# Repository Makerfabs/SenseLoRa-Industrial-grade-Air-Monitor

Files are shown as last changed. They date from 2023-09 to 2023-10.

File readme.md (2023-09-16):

# SenseLoRa Industrial grade Air Monitor

```c++
/*
Version:		V1.0
Author:			Vincent
Create Date:	2023/9/16
Note:

*/
```
# Makerfabs

[Makerfabs home page](https://www.makerfabs.com/)

[Makerfabs Wiki](https://wiki.makerfabs.com/)

# How To Use

## Arduino Complier Option

**If you have any questions，such as how to install the development board, how to download the code, how to install the library. Please refer to :[Makerfabs_FAQ](https://github.com/Makerfabs/Makerfabs_FAQ)**

- Install board : ESP32 Version 2.0.11
- Select "ESP32-S3"
- Select Erase All Flash
- Upload codes

Arduino libraries:

- RadioLib 4.6.0
- Adafruit_Unified_Sensor 1.1.9
- Adafruit_AHT10 0.1.0
- Adafruit_BusIO 1.14.1
- Adafruit_SGP30_Sensor 2.0.0
- BH1750 1.3.0

## Lora Data Format

```json

{
	"ID": "AirM01",
	"COUNT": 22,
	"SLEEP": 3600,
	"bat": 3.48,
	"temp": 0.00,
	"humi": 0.00,
	"eco2": 0.00,
	"lux": 0.00
}

 ```

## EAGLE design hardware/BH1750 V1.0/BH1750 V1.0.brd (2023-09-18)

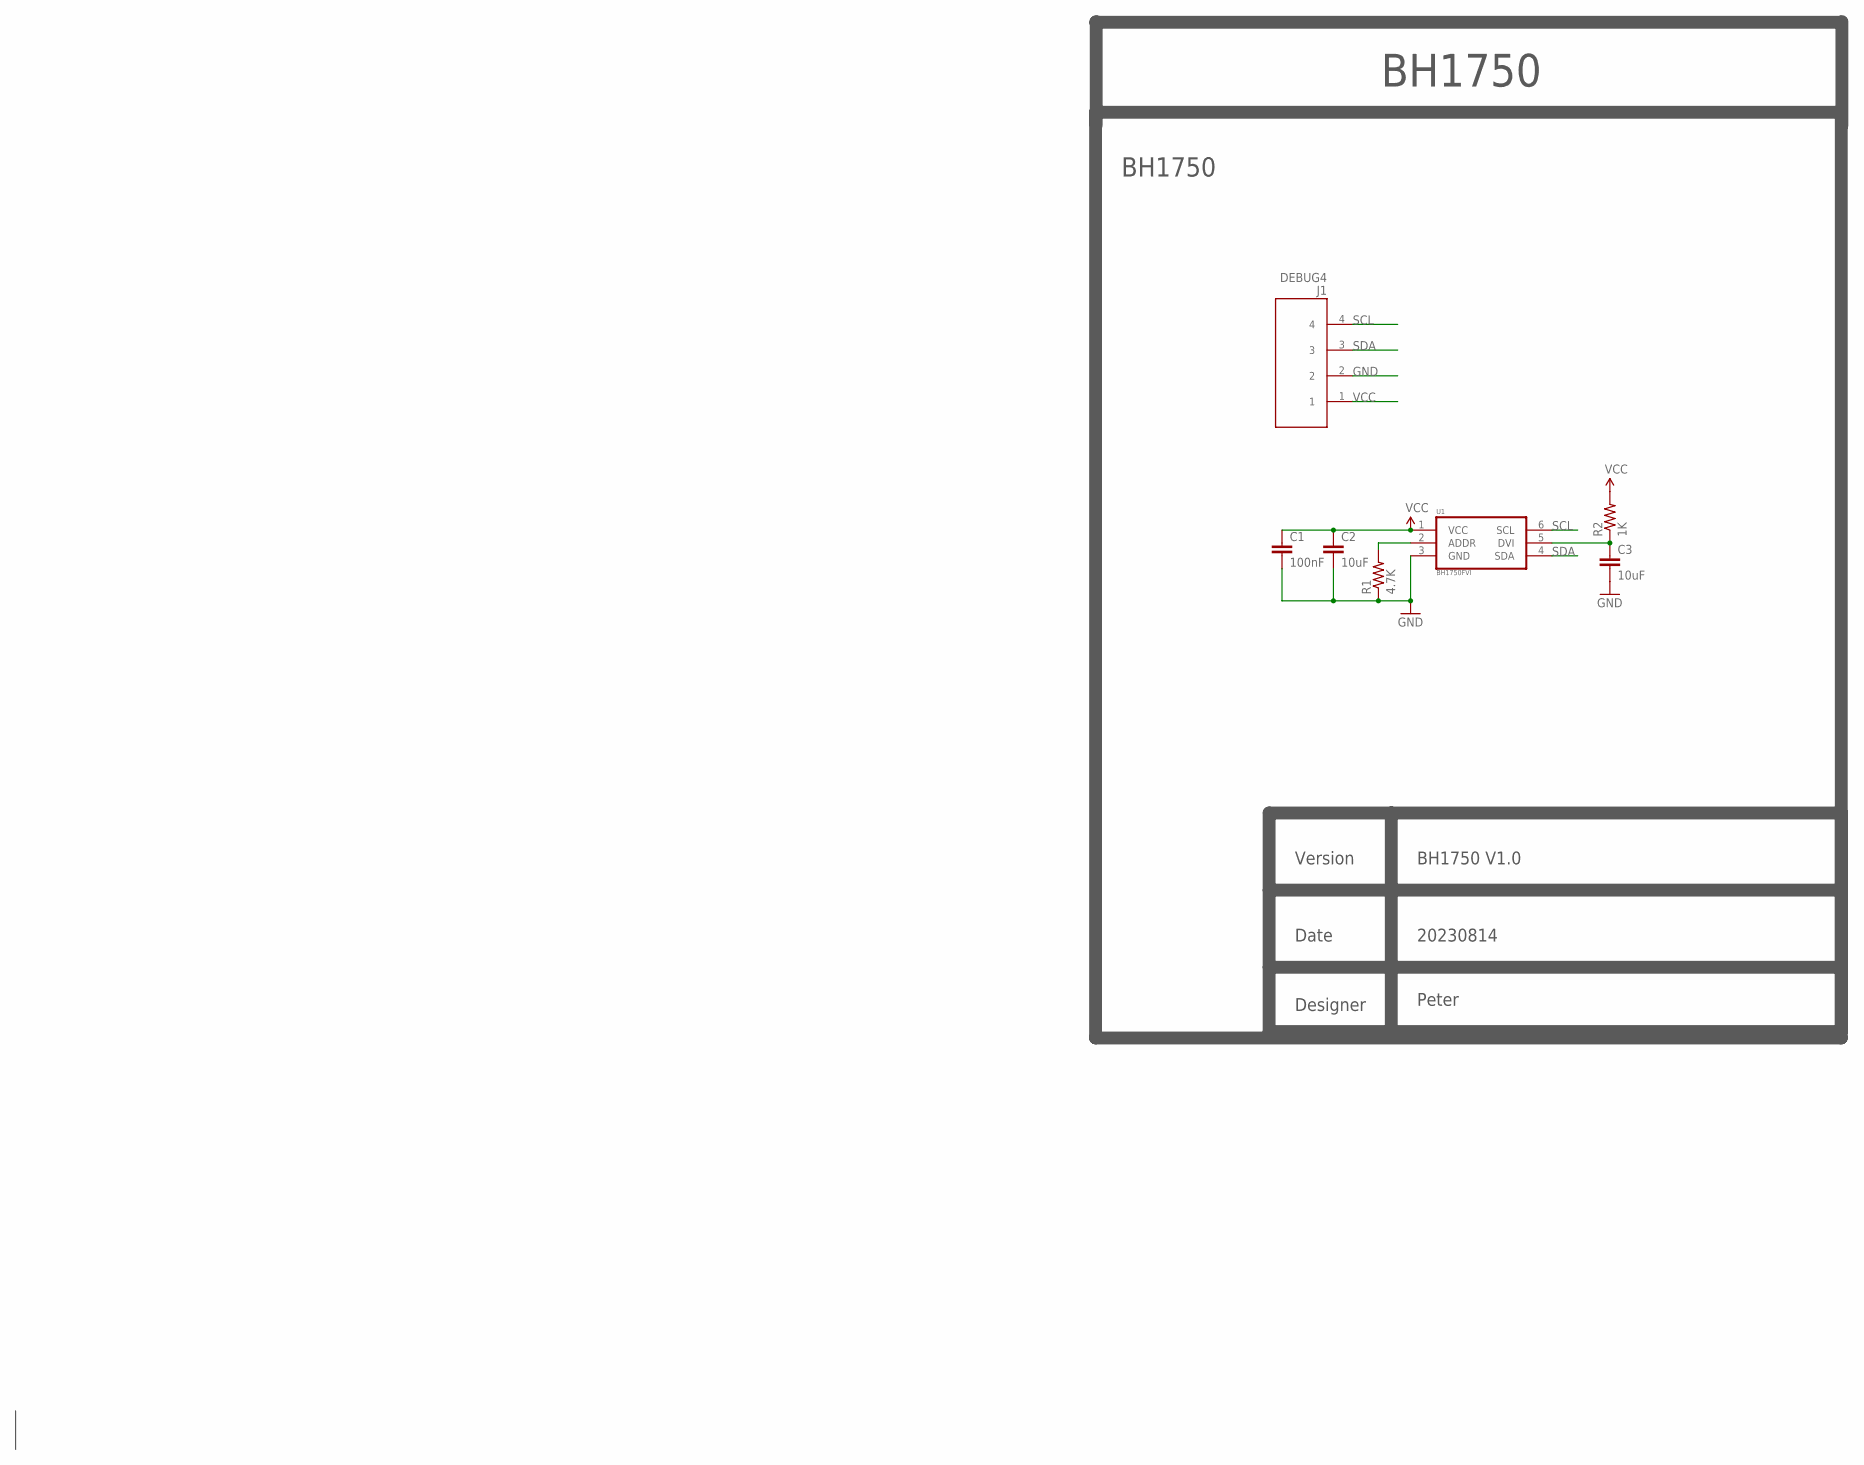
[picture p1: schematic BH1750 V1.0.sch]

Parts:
C1: 100nF; C0603
C2, C3: 10uF; C0603
J1: DEBUG4; DEBUG*4
R1: 4.7K; R0603
R2: 1K; R0603
U1: BH1750FVI; WSOF6I

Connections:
GND: C1.2, C2.2, C3.2, J1.2, R1.1, U1.3 (GND)
unnamed: C3.1, R2.1, U1.5 (DVI)
unnamed: R1.2, U1.2 (ADDR)
SCL: J1.4, U1.6 (SCL)
SDA: J1.3, U1.4 (SDA)
VCC: C1.1, C2.1, J1.1, R2.2, U1.1 (VCC)

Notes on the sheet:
BH1750
Version
Date
Designer
BH1750 V1.0
20230814
Peter

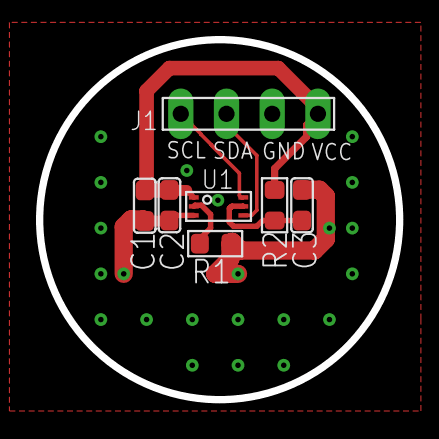
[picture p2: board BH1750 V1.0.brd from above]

Board: 2 copper layers, 20.0 x 20.0 mm, 7 parts (0 on the bottom side), 6 nets.

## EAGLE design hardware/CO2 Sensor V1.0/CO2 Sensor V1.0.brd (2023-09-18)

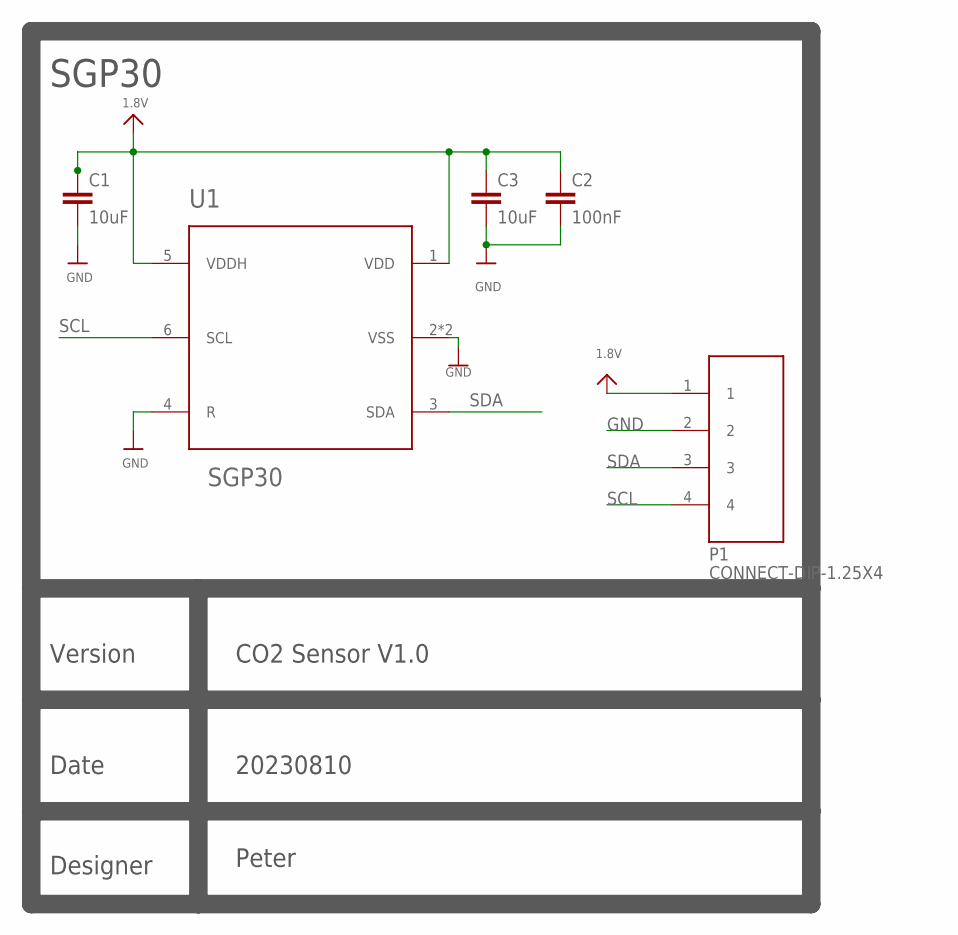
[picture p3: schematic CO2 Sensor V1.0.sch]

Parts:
C1, C3: 10uF; C0603
C2: 100nF; C0603
P1: CONNECT-DIP-1.25X4
U1: SGP30

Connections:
1.8V: C1.1, C2.1, C3.1, P1.1, U1.1 (VDD), U1.5 (VDDH)
GND: C1.2, C2.2, C3.2, P1.2, U1.2 (VSS), U1.4 (R), U1.P$7 (VSS)
SCL: P1.4, U1.6 (SCL)
SDA: P1.3, U1.3 (SDA)

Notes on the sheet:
Version
Date
Designer
CO2 Sensor V1.0
20230810
Peter
SGP30

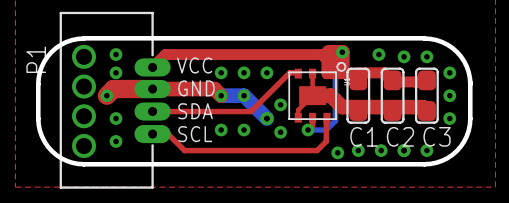
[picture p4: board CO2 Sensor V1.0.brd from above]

Board: 2 copper layers, 24.0 x 7.0 mm, 5 parts (0 on the bottom side), 4 nets.

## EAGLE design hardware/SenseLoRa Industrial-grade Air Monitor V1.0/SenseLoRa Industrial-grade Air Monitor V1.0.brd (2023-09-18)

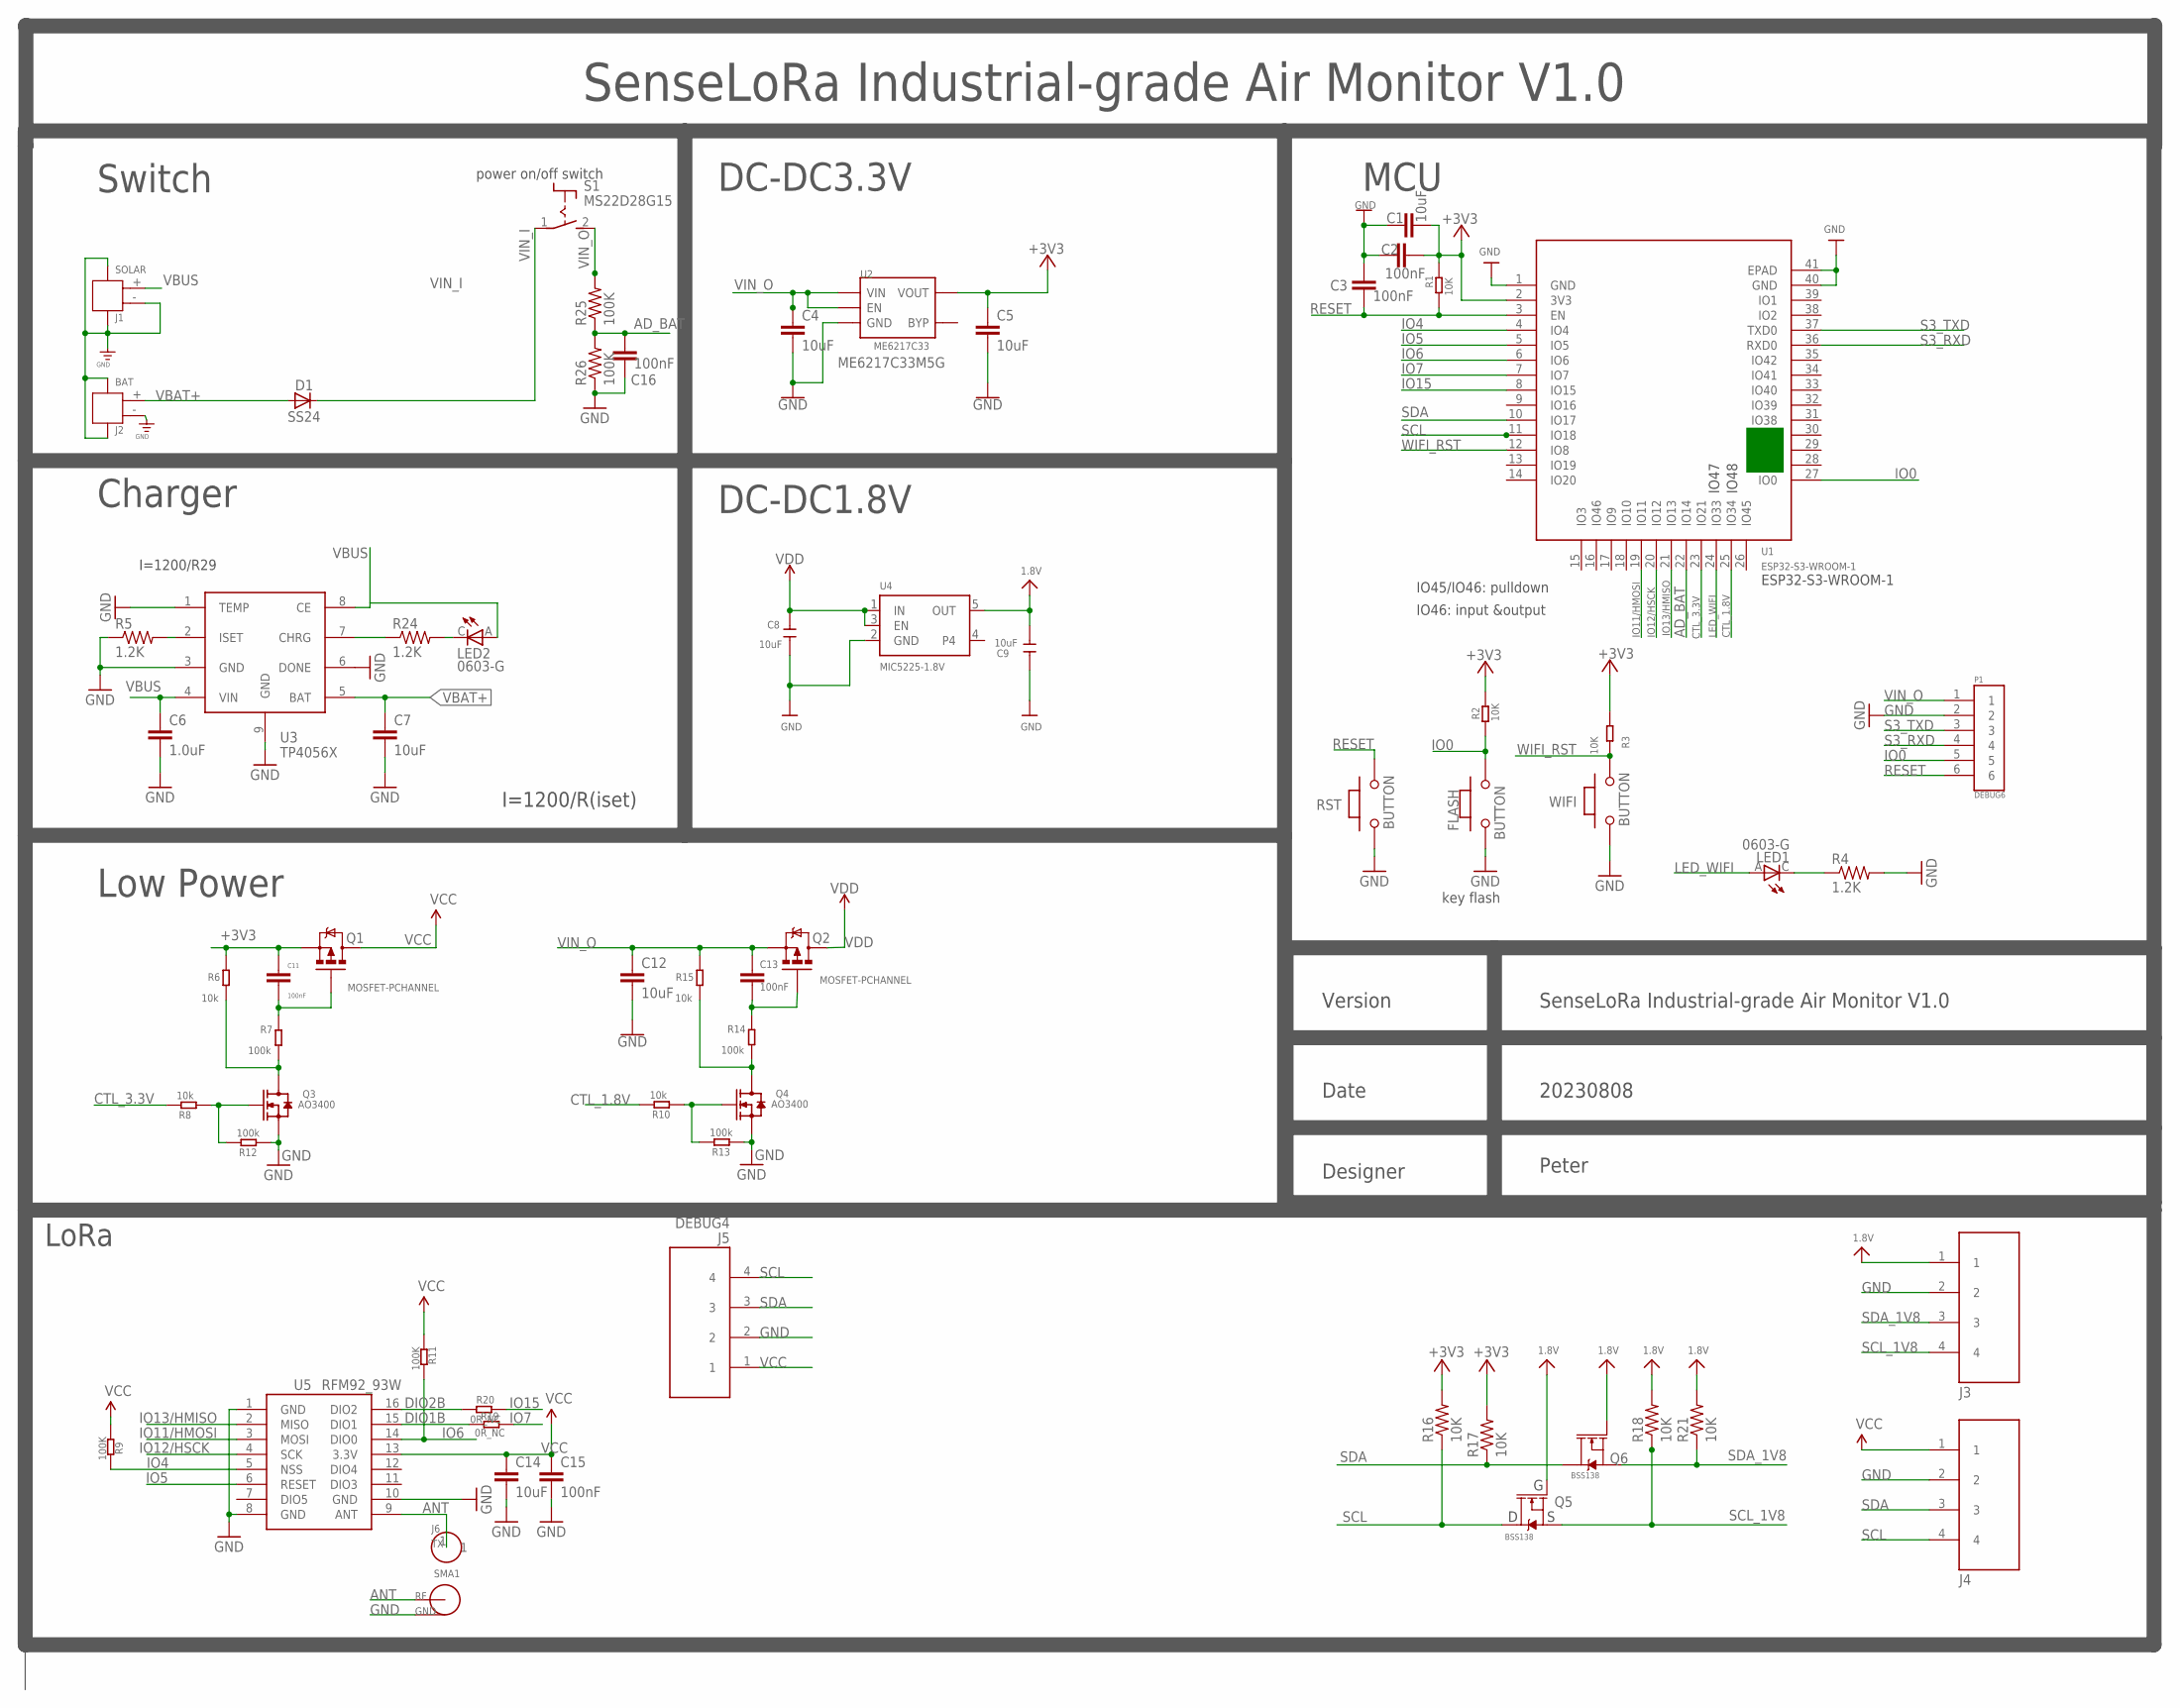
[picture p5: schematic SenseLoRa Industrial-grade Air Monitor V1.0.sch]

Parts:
C1, C4, C5, C7, C12, C14: 10uF; C0603
C2, C3, C11, C13, C15, C16: 100nF; C0603
C6: 1.0uF; C0603
C8, C9: 10uF; 0603
D1: SS24; DO-214AC
FLASH: BUTTON; 157SW
J1: SOLAR; HW2-SMD-2.0-90D
J2: BAT; HW2-SMD-2.0-90D
J3, J4: CONNNECT-SMD-1.25X4P
J5: DEBUG4; DEBUG*4
J6: TX; 1P-100/50MIL
LED1, LED2: 0603-G; LED0603
P1: DEBUG6; DEBUG*6
Q1, Q2: MOSFET-PCHANNEL; SOT23-3
Q3, Q4: AO3400; SOT23@1
Q5, Q6: BSS138; SOT23-3
R1, R2, R3, R16, R17, R18, R21: 10K; R0603
R4, R5, R24: 1.2K; R0603
R6, R8, R10, R15: 10k; R0603
R7, R12, R13, R14: 100k; R0603
R9, R11, R25, R26: 100K; R0603
R19, R20: 0R_NC; R0603
RST: BUTTON; 157SW
S1: MS22D28G15; S-MS22D28G15
SMA1: SMA-KWE
U1: ESP32-S3-WROOM-1; ESP32-­S2-­SOLO
U2: ME6217C33; SOT23-5
U3: TP4056X; SOP8-1.27P
U4: MIC5225-1.8V; SOT23-5
U5: RFM92_93W
WIFI: BUTTON; 157SW

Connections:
1.8V: C9.1, J3.1, Q5.1 (G), Q6.1 (G), R18.2, R21.2, U4.5 (OUT)
+3V3: C1.2, C2.2, C5.1, C11.1, Q1.2 (S), R1.2, R2.2, R3.2, R6.2, R16.2, R17.2, U1.2 (3V3), U2.5 (VOUT)
AD_BAT: C16.2, R25.1, R26.2, U1.22 (IO14)
ANT: J6.1, SMA1.1 (SIG), U5.9 (ANT)
CTL_1.8V: R10.2, U1.25 (IO34)
CTL_3.3V: R8.2, U1.23 (IO21)
DIO1B: R19.2, U5.15 (DIO1)
DIO2B: R20.2, U5.16 (DIO2)
GND: C1.1, C2.1, C3.2, C4.2, C5.2, C6.2, C7.2, C8.2, C9.2, C12.2, C14.2, C15.2, C16.1, FLASH.1, J1.3, J1.4, J1.- (2), J2.3, J2.4, J2.- (2), J3.2, J4.2, J5.2, P1.2, Q3.2 (S), Q4.2 (S), R4.2, R5.1, R12.1, R13.1, R26.1, RST.1, SMA1.2 (GND), SMA1.3 (GND), SMA1.4 (GND), SMA1.5 (GND), U1.1 (GND), U1.40 (GND), U1.41 (EPAD), U2.2 (GND), U3.1 (TEMP), U3.3 (GND), U3.6 (DONE), U3.9 (GND), U4.2 (GND), U5.1 (GND), U5.8 (GND), U5.10 (GND), WIFI.1
IO0: FLASH.2, P1.5, R2.1, U1.27 (IO0)
IO4: R9.1, U1.4 (IO4), U5.5 (NSS)
IO5: U1.5 (IO5), U5.6 (RESET)
IO6: R11.1, U1.6 (IO6), U5.14 (DIO0)
IO7: R19.1, U1.7 (IO7)
IO11/HMOSI: U1.19 (IO11), U5.3 (MOSI)
IO12/HSCK: U1.20 (IO12), U5.4 (SCK)
IO13/HMISO: U1.21 (IO13), U5.2 (MISO)
IO15: R20.1, U1.8 (IO15)
ISET: R5.2, U3.2 (ISET)
LED_WIFI: LED1.A, U1.24 (IO33)
unnamed: LED1.C, R4.1
unnamed: R24.1, U3.7 (CHRG)
unnamed: LED2.C, R24.2
unnamed: C13.2, Q2.1 (G), R14.2
unnamed: Q4.1 (G), R10.1, R13.2
unnamed: C11.2, Q1.1 (G), R7.2
unnamed: Q3.1 (G), R8.1, R12.2
unnamed: Q3.3 (D), R6.1, R7.1
unnamed: Q4.3 (D), R14.1, R15.1
RESET: C3.1, P1.6, R1.1, RST.2, U1.3 (EN)
S3_RXD: P1.4, U1.36 (RXD0)
S3_TXD: P1.3, U1.37 (TXD0)
SCL: J4.4, J5.4, Q5.3 (D), R16.1, U1.11 (IO18)
SCL_1V8: J3.4, Q5.2 (S), R18.1
SDA: J4.3, J5.3, Q6.3 (D), R17.1, U1.10 (IO17)
SDA_1V8: J3.3, Q6.2 (S), R21.1
VBAT+: C7.1, D1.A, J2.+ (1), U3.5 (BAT)
VBUS: C6.1, J1.+ (1), LED2.A, U3.4 (VIN), U3.8 (CE)
VCC: C14.1, C15.1, J4.1, J5.1, Q1.3 (D), R9.2, R11.2, U5.13 (3.3V)
VDD: C8.1, Q2.3 (D), U4.1 (IN), U4.3 (EN)
VIN_I: D1.C, S1.1
VIN_O: C4.1, C12.1, C13.1, P1.1, Q2.2 (S), R15.2, R25.2, S1.2 (S), U2.1 (VIN), U2.3 (EN)
WIFI_RST: R3.1, U1.12 (IO8), WIFI.2

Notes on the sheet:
DC-DC3.3V
I=1200/R29
ME6217C33M5G
Charger
LoRa
power on/off switch
key flash
Switch
MCU
Low Power
IO45/IO46: pulldown
IO46: input &output
ESP32-S3-WROOM-1
IO47
IO48
I=1200/R(iset)
SenseLoRa Industrial-grade Air Monitor V1.0
Version
Date
Designer
20230808
Peter
DC-DC1.8V

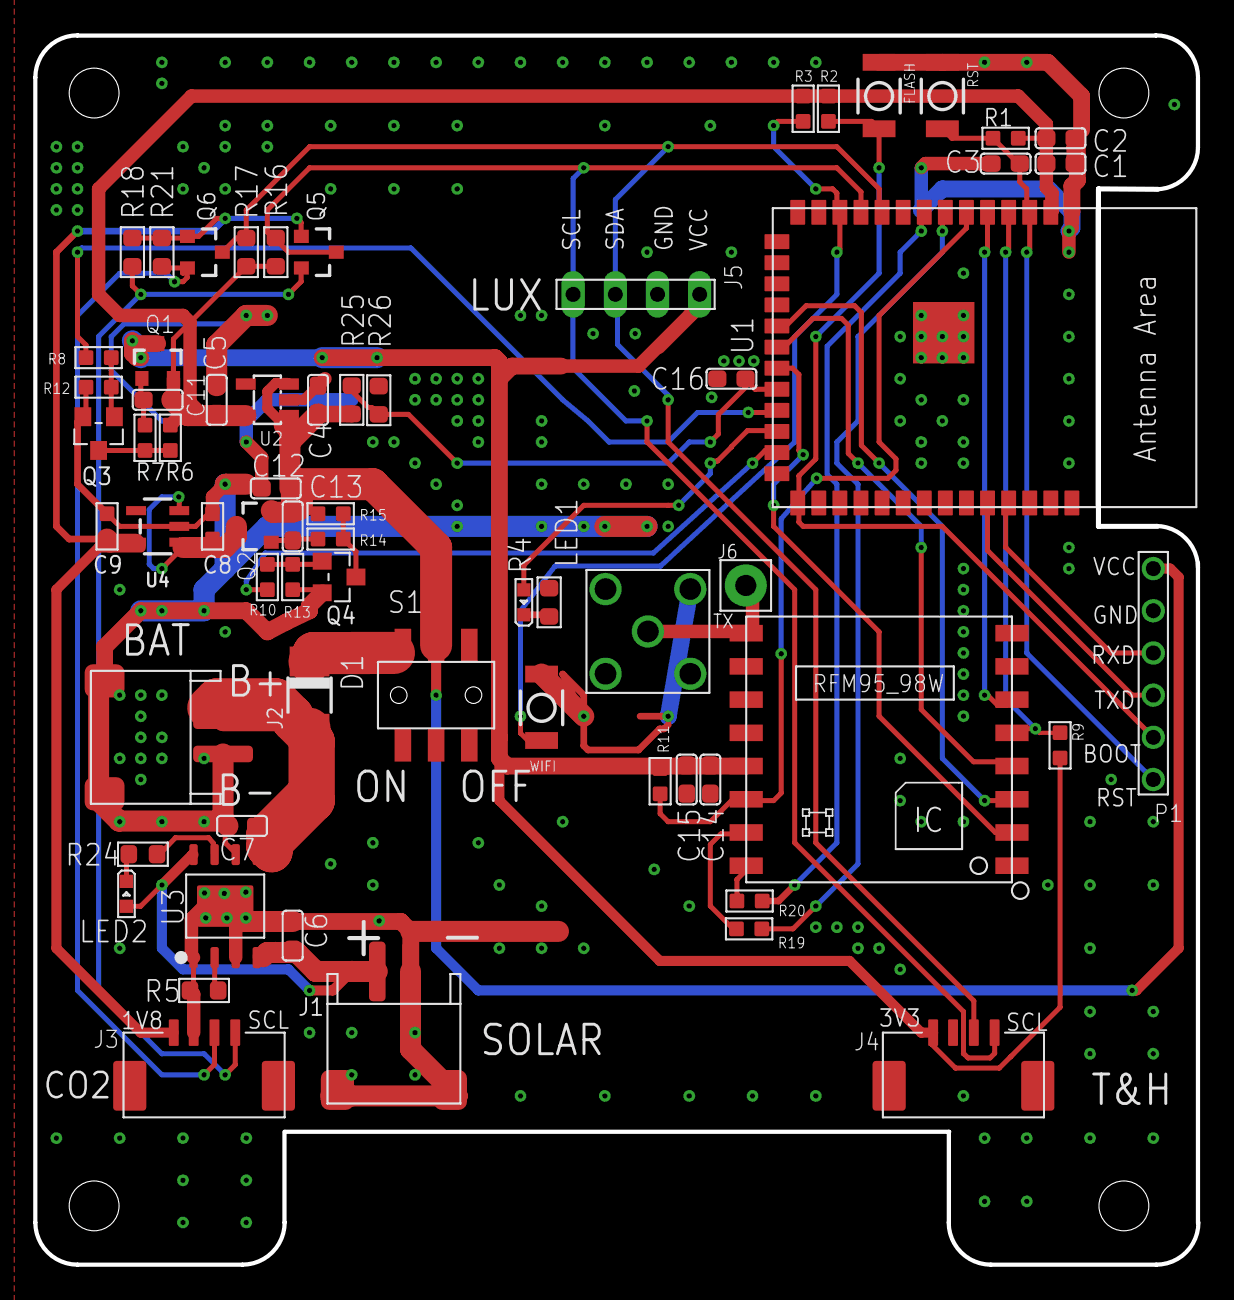
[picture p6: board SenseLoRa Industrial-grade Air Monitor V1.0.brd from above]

Board: 2 copper layers, 70.0 x 74.0 mm, 66 parts (1 on the bottom side), 43 nets.

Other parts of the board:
U$2: MAKERFABS_0.3

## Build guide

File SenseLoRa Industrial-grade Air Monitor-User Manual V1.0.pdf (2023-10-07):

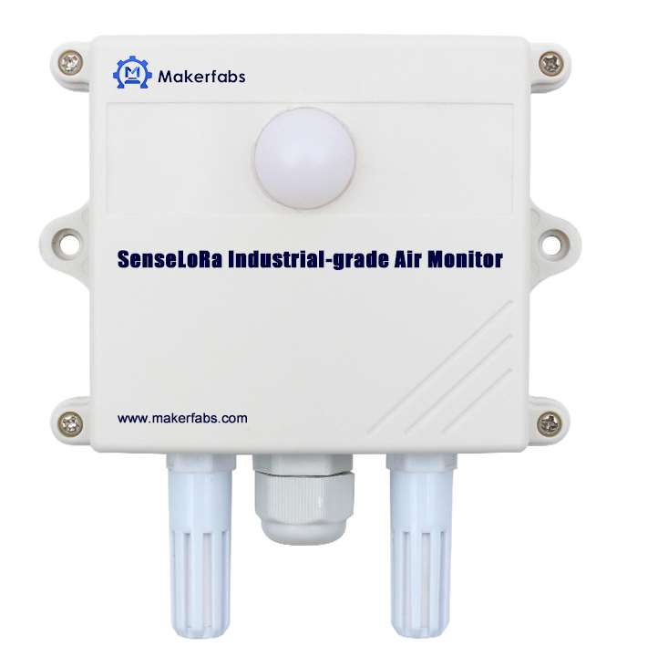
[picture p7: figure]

1 / 9

SenseLoRa Industrial-grade Air Monitor

Version： V1.0
Data： 2023-09-26
Author： Peter

2 / 9

## Contents

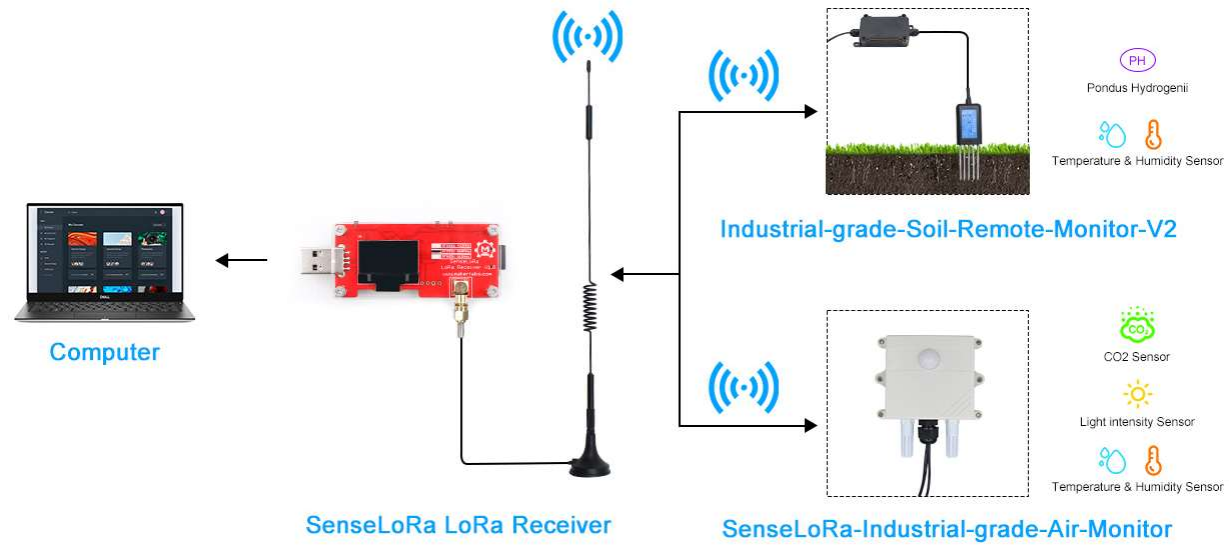
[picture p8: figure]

3 / 9

## 1. Introduction

### 1.1 Function

SenseLoRa Industrial-grade Air Monitor is an industrial-grade wireless sensing device. It can monitor air temperature, air humidity, CO2 concentration and light intensity and broadcast all the sensor data Periodically via LoRa P2P, with Jason format, this LoRa signal can be received by Makerfabs LoRa receiver, and thus to display/record/analyz e on PC.

The product supports the LoRa protocol, which achieves low power consumption, long distance and security.
The hardware is simple to operate and easy to deploy, data API services are convenient.
The products can be used in fields and greenhouses.

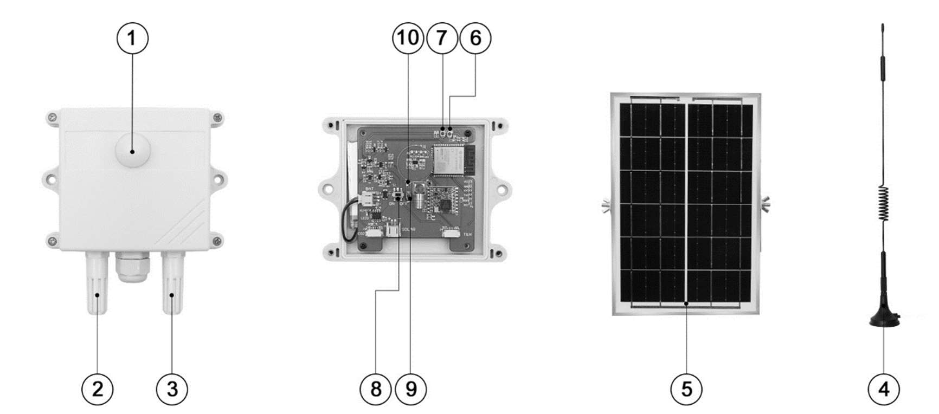
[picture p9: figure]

4 / 9

### 1.2 General description

① Light intensity Sensor
② CO2 Sensor
③ Temperature & Humidity Sensor ④ Antenna
⑤ Solar Panel
⑥ Reset button
⑦ Burn button
⑧ Power Switch
⑨ WiFi button
⑩ Status LED

## 2. Installation

### 2.1 Parts List

Description | Specification | PCS
Main Case | 88mm*34mm*18mm | 1
Antenna | 1000mm | 1
Solar Panel | 270 x 160 x 15mm | 1

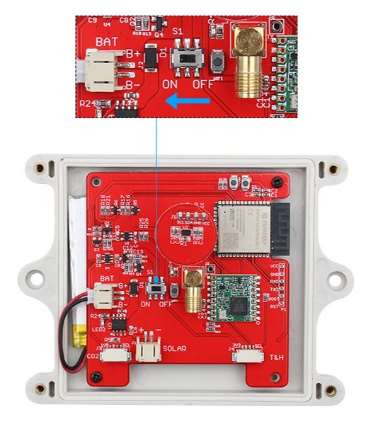
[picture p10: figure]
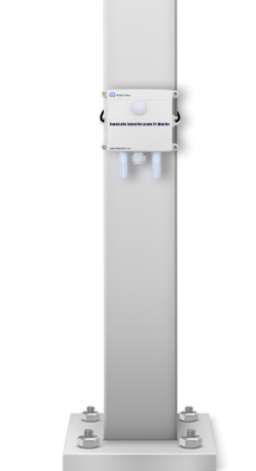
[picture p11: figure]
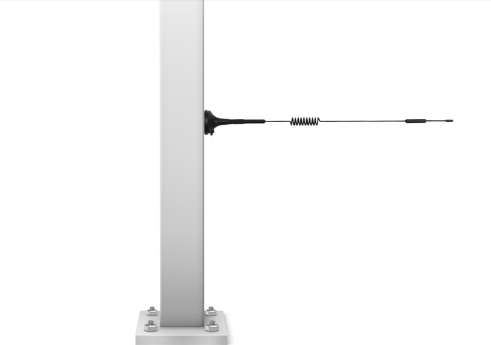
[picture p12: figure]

5 / 9

### 2.2 Power On

Unscrew 4 screws to open the cover, turn on the switch and lock the screws.

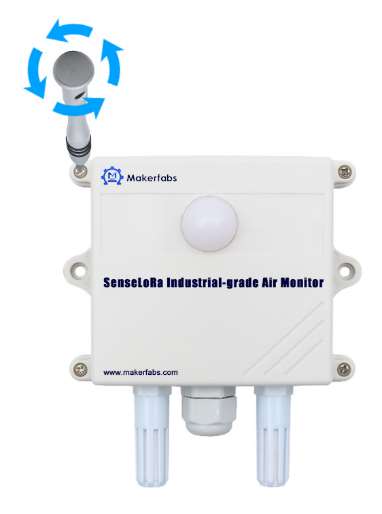
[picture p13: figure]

The product can be fixed on the column, and can also be fixed on the wall through the holes on both sides.

### 2.3 Antenna Installation

The antenna can be secured by a suction cup at the bottom or bound with a cable tie.

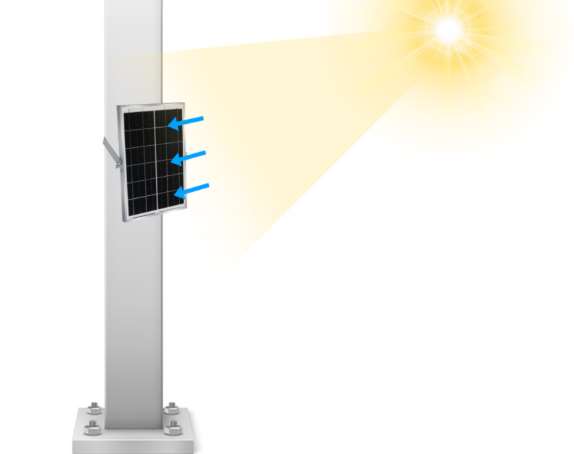
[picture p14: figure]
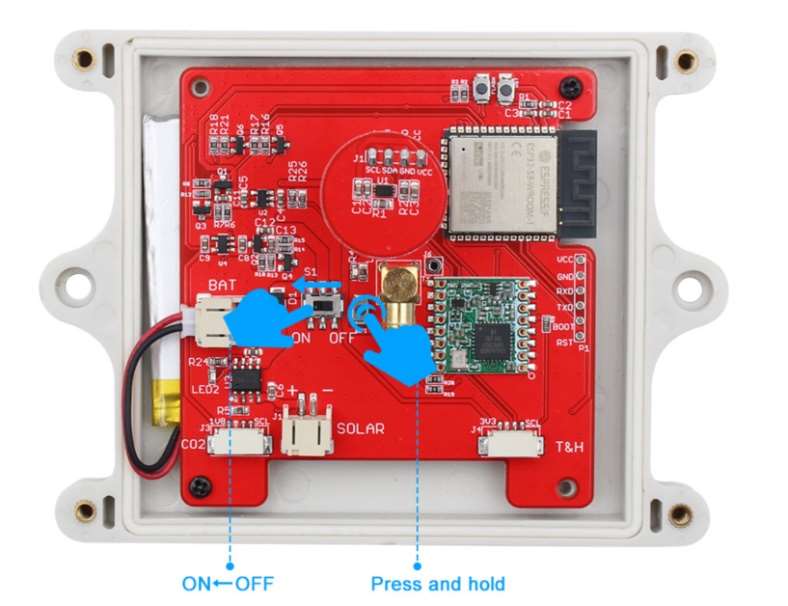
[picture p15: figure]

6 / 9

### 2.4 Solar Panel Installation

Solar panels should be placed in a place that can receive the most sunlight. It can be fixed to posts or placed on the ground.

2.5 （***Optional***）ID and Interval Time Settings

If multiple products are implemented, ID need to be set for different module. The default ID is AirM01 and the interval time is 3600 seconds. You can set the product ID and interval time by:
① After opening the product shell, find the Power Switch and WiFi button.
② Press and hold the WiFi button, and then flip the switch to the ON position.

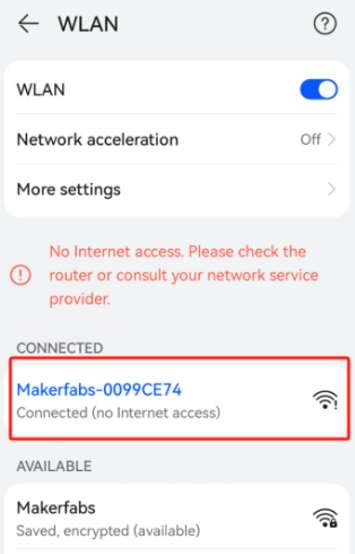
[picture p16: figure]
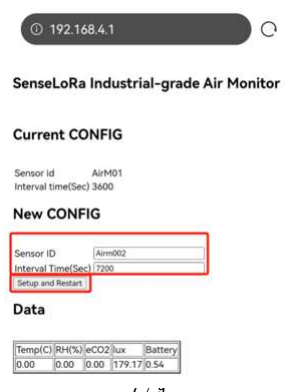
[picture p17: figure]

7 / 9

③ Turn on your phone's wireless network Settings to view WiFi hotspots.
④ Select the following network “makerfabs-XXXXXXXX ” and enter the password “12345678 ”

⑤ After the phone is connected to the WiFi of the product, type “192.168.4.1” in the URL bar of the browser.
⑥ Enter the any name of the product and the interval time in the box.

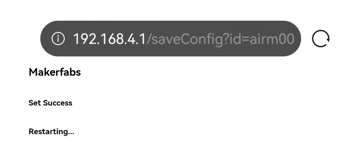
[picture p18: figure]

8 / 9

⑦ Click Setup and Restart, Then the page prompts that the setting is successful. Product start work.

⑧ Close the shell and lock the four screws.

## 3. Data Transmission Management

The product's sensor data will be sent in JSON format: {
"ID": "AirM01", | // Sensor ID
"COUNT": 1, | //Data Reception Times
"SLEEP": 3600, | //Interval Time (s)
"bat": 4.10, | //Battery Voltage(V)
"temp": 27.60, | //Air Temperature (℃)
"humi": 35.00, | //Relative Humidity(％RH)
"eco2": 486, | // CO2 Concentration (ppm)
"lux": 155 | // Luminous Intensity(Lux)
}

9 / 9

## 4. Specifications

Model | SenseLoRa Industrial-grade Air

Monitor
Li-ion Battery Power supply | 3.7V / 1000mAh
Solar Panel | 6V / 6W
Frequency Bands | EU868/ US915
Air temperature | -40~85°C ±0.1℃
Air humidity | 0~100%RH ±1.5%RH
CO2 | 400 to 60000 ppm 土(30 ppm)
Luminous intensity | 1~65535 Lux ±20%
Physical characteristics
Dimensions (height x width x Depth) | 122 x 110 x 52mm
Solar Panel | 270 x 160 x 15mm
Weight main unit | 161.8g
Antenna length | 1000mm
Operating conditions
Temperature -40°C to +80°C
Relative humidity 15% to 90% (no condensation) Storage conditions
Temperature -20°C to +50°C
Relative humidity 15% to 90% (no condensation)

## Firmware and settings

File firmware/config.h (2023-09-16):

#ifndef CONFIG_H
#define CONFIG_H

#define AP_SSID "Makerfabs-"
#define AP_PWD "12345678"

#define SENSOR_5_PIN
// #define SENSOR_3_PIN

#define DEFAULT_SENSOR_ID "AirM01"
#define DEFAULT_SLEEP_TIME "3600"

#define SUCCESS 1
#define ERROR 0

#define NVS_DATA_LENGTH 20

#define uS_TO_S_FACTOR 1000000ULL /* Conversion factor for micro seconds to seconds */

// Lora
#define LORA_RST 5
#define LORA_CS 4

#define DIO0 6
#define DIO1 7
#define DIO2 15

#define SPI_MOSI 11
#define SPI_MISO 13
#define SPI_SCK 12

#define FREQUENCY 868.0
#define BANDWIDTH 125.0
#define SPREADING_FACTOR 12
#define CODING_RATE 6
#define OUTPUT_POWER 20
#define PREAMBLE_LEN 8
#define GAIN 0

// Power Control
#define POWER_3V3 21
#define POWER_1V8 48

#define SDA 17
#define SCL 18

#define BUTTON_PIN 8
#define LED_PIN 47

#define BAT_PIN 14

#endif

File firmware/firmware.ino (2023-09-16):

// 使用 4.6.0  版本的库 RadioLib 在文件夹： C:\Users\vincent\Documents\Arduino\libraries\RadioLib
// 使用 2.0.0  版本的库 SPI 在文件夹： C:\Users\vincent\AppData\Local\Arduino15\packages\esp32\hardware\esp32\2.0.11\libraries\SPI
// 使用 2.0.0  版本的库 Wire 在文件夹： C:\Users\vincent\AppData\Local\Arduino15\packages\esp32\hardware\esp32\2.0.11\libraries\Wire
// 使用 1.1.9  版本的库 Adafruit_Unified_Sensor 在文件夹： C:\Users\vincent\Documents\Arduino\libraries\Adafruit_Unified_Sensor
// 使用 0.1.0  版本的库 Adafruit_AHT10 在文件夹： C:\Users\vincent\Documents\Arduino\libraries\Adafruit_AHT10
// 使用 1.14.1  版本的库 Adafruit_BusIO 在文件夹： C:\Users\vincent\Documents\Arduino\libraries\Adafruit_BusIO
// 使用 2.0.0  版本的库 Adafruit_SGP30_Sensor 在文件夹： C:\Users\vincent\Documents\Arduino\libraries\Adafruit_SGP30_Sensor
// 使用 1.3.0  版本的库 BH1750 在文件夹： C:\Users\vincent\Documents\Arduino\libraries\BH1750
// 使用 2.0.0  版本的库 WiFi 在文件夹： C:\Users\vincent\AppData\Local\Arduino15\packages\esp32\hardware\esp32\2.0.11\libraries\WiFi
// "C:\\Users\\vincent\\AppData\\Local\\Arduino15\\packages\\esp32\\tools\\xtensa-esp32s3-elf-gcc\\esp-2021r2-patch5-8.4.0/bin/xtensa-esp32s3-elf-size" -A "C:\\Users\\vincent\\AppData\\Local\\Temp\\arduino_build_951611/esp32_lora_485.ino.elf"
// 项目使用了 758085 字节，占用了 (57%) 程序存储空间。最大为 1310720 字节。
// 全局变量使用了46360字节，(14%)的动态内存，余留281320字节局部变量。最大为327680字节。

#include <RadioLib.h>
#include <SPI.h>
#include <Wire.h>
#include <Adafruit_Sensor.h>
#include <Adafruit_AHT10.h>
#include <Adafruit_SGP30.h>
#include <BH1750.h>

#include "config.h"
#include "web_server.h"

SX1276 radio = new Module(LORA_CS, DIO0, LORA_RST, DIO1, SPI, SPISettings());

// Sensor Config
char sensor_id[NVS_DATA_LENGTH];
char sleep_time[NVS_DATA_LENGTH];

RTC_DATA_ATTR int bootCount = 0;

Adafruit_AHT10 aht;
Adafruit_SGP30 sgp;
BH1750 lightMeter;

float temperature = 0.0;
float humidity = 0.0;
float tvoc = 0.0;
float eCO2 = 0.0;
float H2 = 0.0;
float Ethanol = 0.0;
float lux = 0.0;
float bat_vol = 0.0;
int count = 0;

int init_flag_aht10 = 0;
int init_flag_SGP30 = 0;
int init_flag_BH1750 = 0;

void setup()
{
    pin_init();

    Serial.begin(115200);

    ++bootCount;
    Serial.println("Boot number: " + String(bootCount));
    print_wakeup_reason();

    lora_init();

    // For test
    while (0)
    {
        lora_send_task("AAAA");
        delay(10000);
    }

    sensor_init();

    // Button Check
    wifi_init();

    delay(5000);
}

void loop()
{
    Serial.println("Reading 20 times...");
    // Send three time and sleep

    if (0) // For test
    {
        read_bat();
        value_report();
        check_count(&count);
        record_count(++count);

        String temp = "";
        temp = lora_msg_create();
        lora_send_task(temp);
        delay(2000);
    }
    else
        for (int i = 0; i < 20; i++)
        {
            sensor_read();
            value_report();

            String temp = "";
            if (i > 18)
            {
                check_count(&count);
                record_count(++count);
                temp = lora_msg_create();
                lora_send_task(temp);
            }
            delay(2000);
        }

    // Sleep
    digitalWrite(POWER_3V3, 0);
    digitalWrite(POWER_1V8, 0);

    int sleep_s = atoi(sleep_time);
    esp_sleep_enable_timer_wakeup(sleep_s * uS_TO_S_FACTOR);
    Serial.println("Setup ESP32 to sleep for every " + String(sleep_s) + " Seconds");

    Serial.println("Going to sleep now");
    Serial.flush();
    esp_deep_sleep_start();
    Serial.println("This will never be printed");
}

// Hardware init

void pin_init()
{
    pinMode(LORA_CS, OUTPUT);
    pinMode(POWER_3V3, OUTPUT);
    pinMode(POWER_1V8, OUTPUT);
    pinMode(BUTTON_PIN, INPUT);
    pinMode(LED_PIN, OUTPUT);
    pinMode(BAT_PIN, INPUT);

    digitalWrite(POWER_3V3, 1);
    digitalWrite(POWER_1V8, 1);
    digitalWrite(LED_PIN, 1);

    delay(100);
}

void lora_init()
{
    SPI.begin(SPI_SCK, SPI_MISO, SPI_MOSI);

    Serial.print(F("[SX1276] Initializing ... "));

    int state = radio.begin(FREQUENCY, BANDWIDTH, SPREADING_FACTOR, CODING_RATE, SX127X_SYNC_WORD, OUTPUT_POWER, PREAMBLE_LEN, GAIN);
    if (state == ERR_NONE)
    {
        Serial.println(F("success!"));
    }
    else
    {
        Serial.print(F("failed, code "));
        Serial.println(state);
        while (true)
            ;
    }
}

void lora_send_task(String data)
{
    Serial.println(data);
    int state = radio.transmit(data.c_str());
    if (state == ERR_NONE)
    {
        // the packet was successfully transmitted
        Serial.println(F(" success!"));

        // print measured data rate
        Serial.print(F("[SX1276] Datarate:\t"));
        Serial.print(radio.getDataRate());
        Serial.println(F(" bps"));
    }
    else if (state == ERR_PACKET_TOO_LONG)
    {
        // the supplied packet was longer than 256 bytes
        Serial.println(F("too long!"));
    }
    else if (state == ERR_TX_TIMEOUT)
    {
        // timeout occurred while transmitting packet
        Serial.println(F("timeout!"));
    }
    else
    {
        // some other error occurred
        Serial.print(F("failed, code "));
        Serial.println(state);
    }
}

// Soil Sensor
void sensor_init()
{
    // SDA SCL
    Wire.begin(SDA, SCL);

    if (!aht.begin())
        Serial.println("SGP30 not found.");
    else
        init_flag_aht10 = 1;

    if (!sgp.begin())
        Serial.println("SGP30 not found.");
    else
        init_flag_SGP30 = 1;

    if (!lightMeter.begin())
        Serial.println("BH1750 not found.");
    else
        init_flag_BH1750 = 1;
}

void sensor_read()
{
    if (init_flag_aht10)
        read_aht10();
    if (init_flag_SGP30)
        read_SGP30();
    if (init_flag_BH1750)
        read_BH1750();
    read_bat();
}

void value_report()
{
    Serial.print("Temperature: ");
    Serial.print(temperature);
    Serial.println(" degrees C");
    Serial.print("Humidity: ");
    Serial.print(humidity);
    Serial.println("% rH");

    Serial.print("TVOC ");
    Serial.print(tvoc);
    Serial.print(" ppb\t");
    Serial.print("eCO2 ");
    Serial.print(eCO2);
    Serial.println(" ppm");

    Serial.print("Raw H2 ");
    Serial.print(H2);
    Serial.print(" \t");
    Serial.print("Raw Ethanol ");
    Serial.print(Ethanol);
    Serial.println("");

    Serial.print("Light: ");
    Serial.print(lux);
    Serial.println(" lx");

    Serial.print("Bat: ");
    Serial.print(bat_vol);
    Serial.println(" V");
}

// Lora send task
String lora_msg_create()
{
    String temp = "{";
    temp = temp + "\"ID\":\"" + sensor_id + "\",\"COUNT\":" + count + ",\"SLEEP\":" + sleep_time + ",";
    temp = temp + "\"bat\":" + bat_vol + ",";
    temp = temp + "\"temp\":" + temperature + ",";
    temp = temp + "\"humi\":" + humidity + ",";
    // temp = temp + "\"tvoc\":" + tvoc + ",";
    temp = temp + "\"eco2\":" + eCO2 + ",";
    // temp = temp + "\"h2\":" + H2 + ",";
    // temp = temp + "\"Ethanol\":" + Ethanol + ",";
    temp = temp + "\"lux\":" + lux + "}";

    return temp;
}

uint32_t getAbsoluteHumidity(float temperature, float humidity)
{
    // approximation formula from Sensirion SGP30 Driver Integration chapter 3.15
    const float absoluteHumidity = 216.7f * ((humidity / 100.0f) * 6.112f * exp((17.62f * temperature) / (243.12f + temperature)) / (273.15f + temperature)); // [g/m^3]
    const uint32_t absoluteHumidityScaled = static_cast<uint32_t>(1000.0f * absoluteHumidity);                                                                // [mg/m^3]
    return absoluteHumidityScaled;
}

void read_aht10()
{
    sensors_event_t humi, temp;
    aht.getEvent(&humi, &temp); // populate temp and humidity objects with fresh data
    temperature = temp.temperature;
    humidity = humi.relative_humidity;
}

void read_SGP30()
{
    sgp.setHumidity(getAbsoluteHumidity(temperature, humidity));

    if (!sgp.IAQmeasure())
    {
        Serial.println("Measurement failed");
        return;
    }
    tvoc = sgp.TVOC;
    eCO2 = sgp.eCO2;

    if (!sgp.IAQmeasureRaw())
    {
        Serial.println("Raw Measurement failed");
        return;
    }
    H2 = sgp.rawH2;
    Ethanol = sgp.rawEthanol;
}

void read_BH1750()
{
    lux = lightMeter.readLightLevel();
}

void read_bat()
{
    bat_vol = 3.3 * analogRead(BAT_PIN) / 4096 * 2 + 0.3;
}

void print_wakeup_reason()
{
    esp_sleep_wakeup_cause_t wakeup_reason;

    wakeup_reason = esp_sleep_get_wakeup_cause();

    switch (wakeup_reason)
    {
    case ESP_SLEEP_WAKEUP_EXT0:
        Serial.println("Wakeup caused by external signal using RTC_IO");
        break;
    case ESP_SLEEP_WAKEUP_EXT1:
        Serial.println("Wakeup caused by external signal using RTC_CNTL");
        break;
    case ESP_SLEEP_WAKEUP_TIMER:
        Serial.println("Wakeup caused by timer");
        break;
    case ESP_SLEEP_WAKEUP_TOUCHPAD:
        Serial.println("Wakeup caused by touchpad");
        break;
    case ESP_SLEEP_WAKEUP_ULP:
        Serial.println("Wakeup caused by ULP program");
        break;
    default:
        Serial.printf("Wakeup was not caused by deep sleep: %d\n", wakeup_reason);
        break;
    }
}

float c2f(float c_temp)
{
    return c_temp * 9.0 / 5.0 + 32;
}

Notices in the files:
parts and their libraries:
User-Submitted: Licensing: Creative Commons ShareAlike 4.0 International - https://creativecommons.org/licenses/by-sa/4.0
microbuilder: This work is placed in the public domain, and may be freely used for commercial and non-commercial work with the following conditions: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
